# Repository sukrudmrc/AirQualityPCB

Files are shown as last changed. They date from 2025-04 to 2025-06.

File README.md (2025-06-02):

# AirQualityPCB
This PCB is designed for an air quality monitoring station, with air quality sensors and a LoRa module placed around the STM32F103.
# SYSTEM SCHEMTAIC

# 3D-PCB

# Final PCB 
pcbF

 # SENSORS

SHT31 

"The SHT31 sensor is a highly accurate and stable sensor with low power consumption."

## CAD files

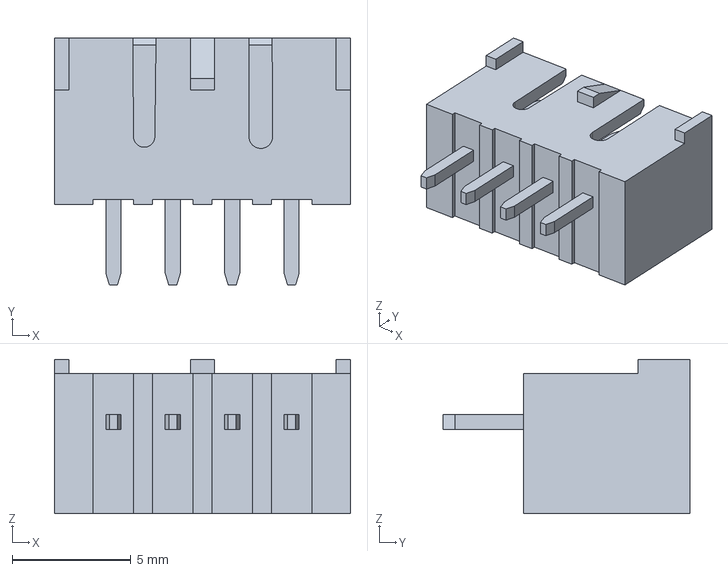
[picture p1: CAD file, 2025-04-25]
PCB_V1/my_comp/35312-0460_igs/353120460.igs
12.5 x 10.4 x 6.50 mm

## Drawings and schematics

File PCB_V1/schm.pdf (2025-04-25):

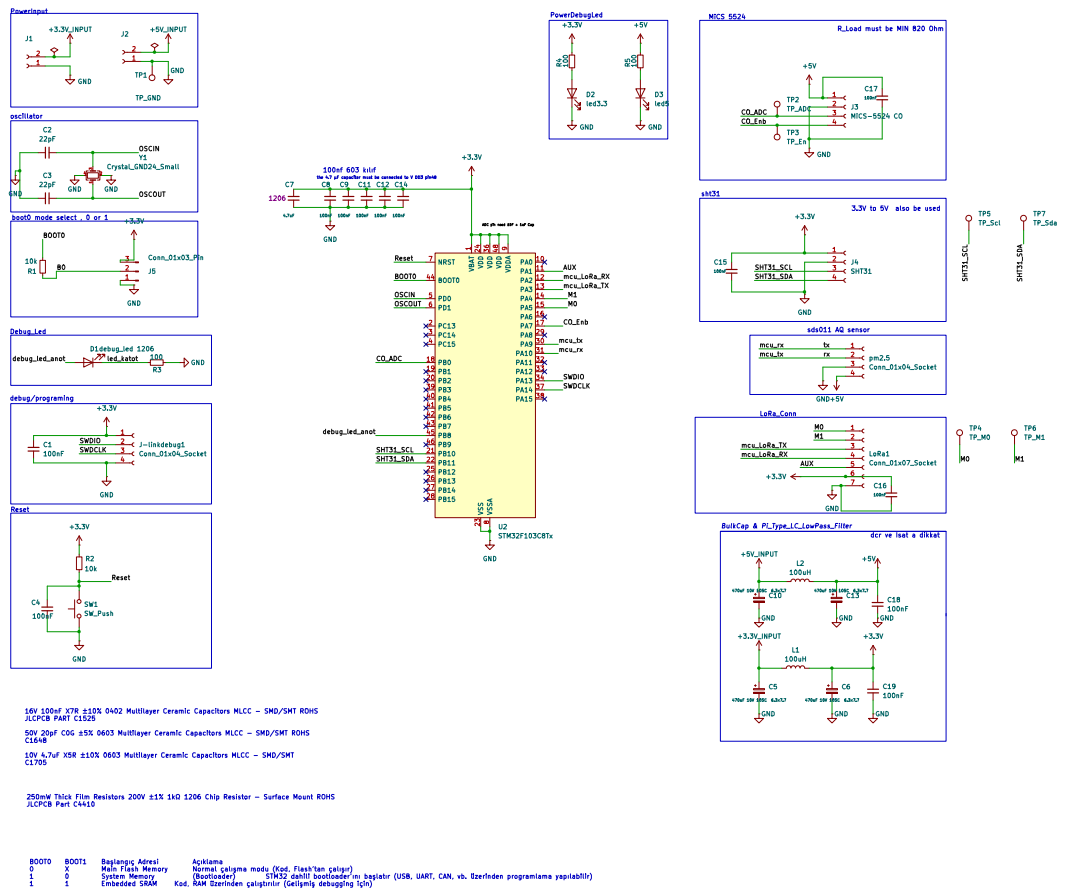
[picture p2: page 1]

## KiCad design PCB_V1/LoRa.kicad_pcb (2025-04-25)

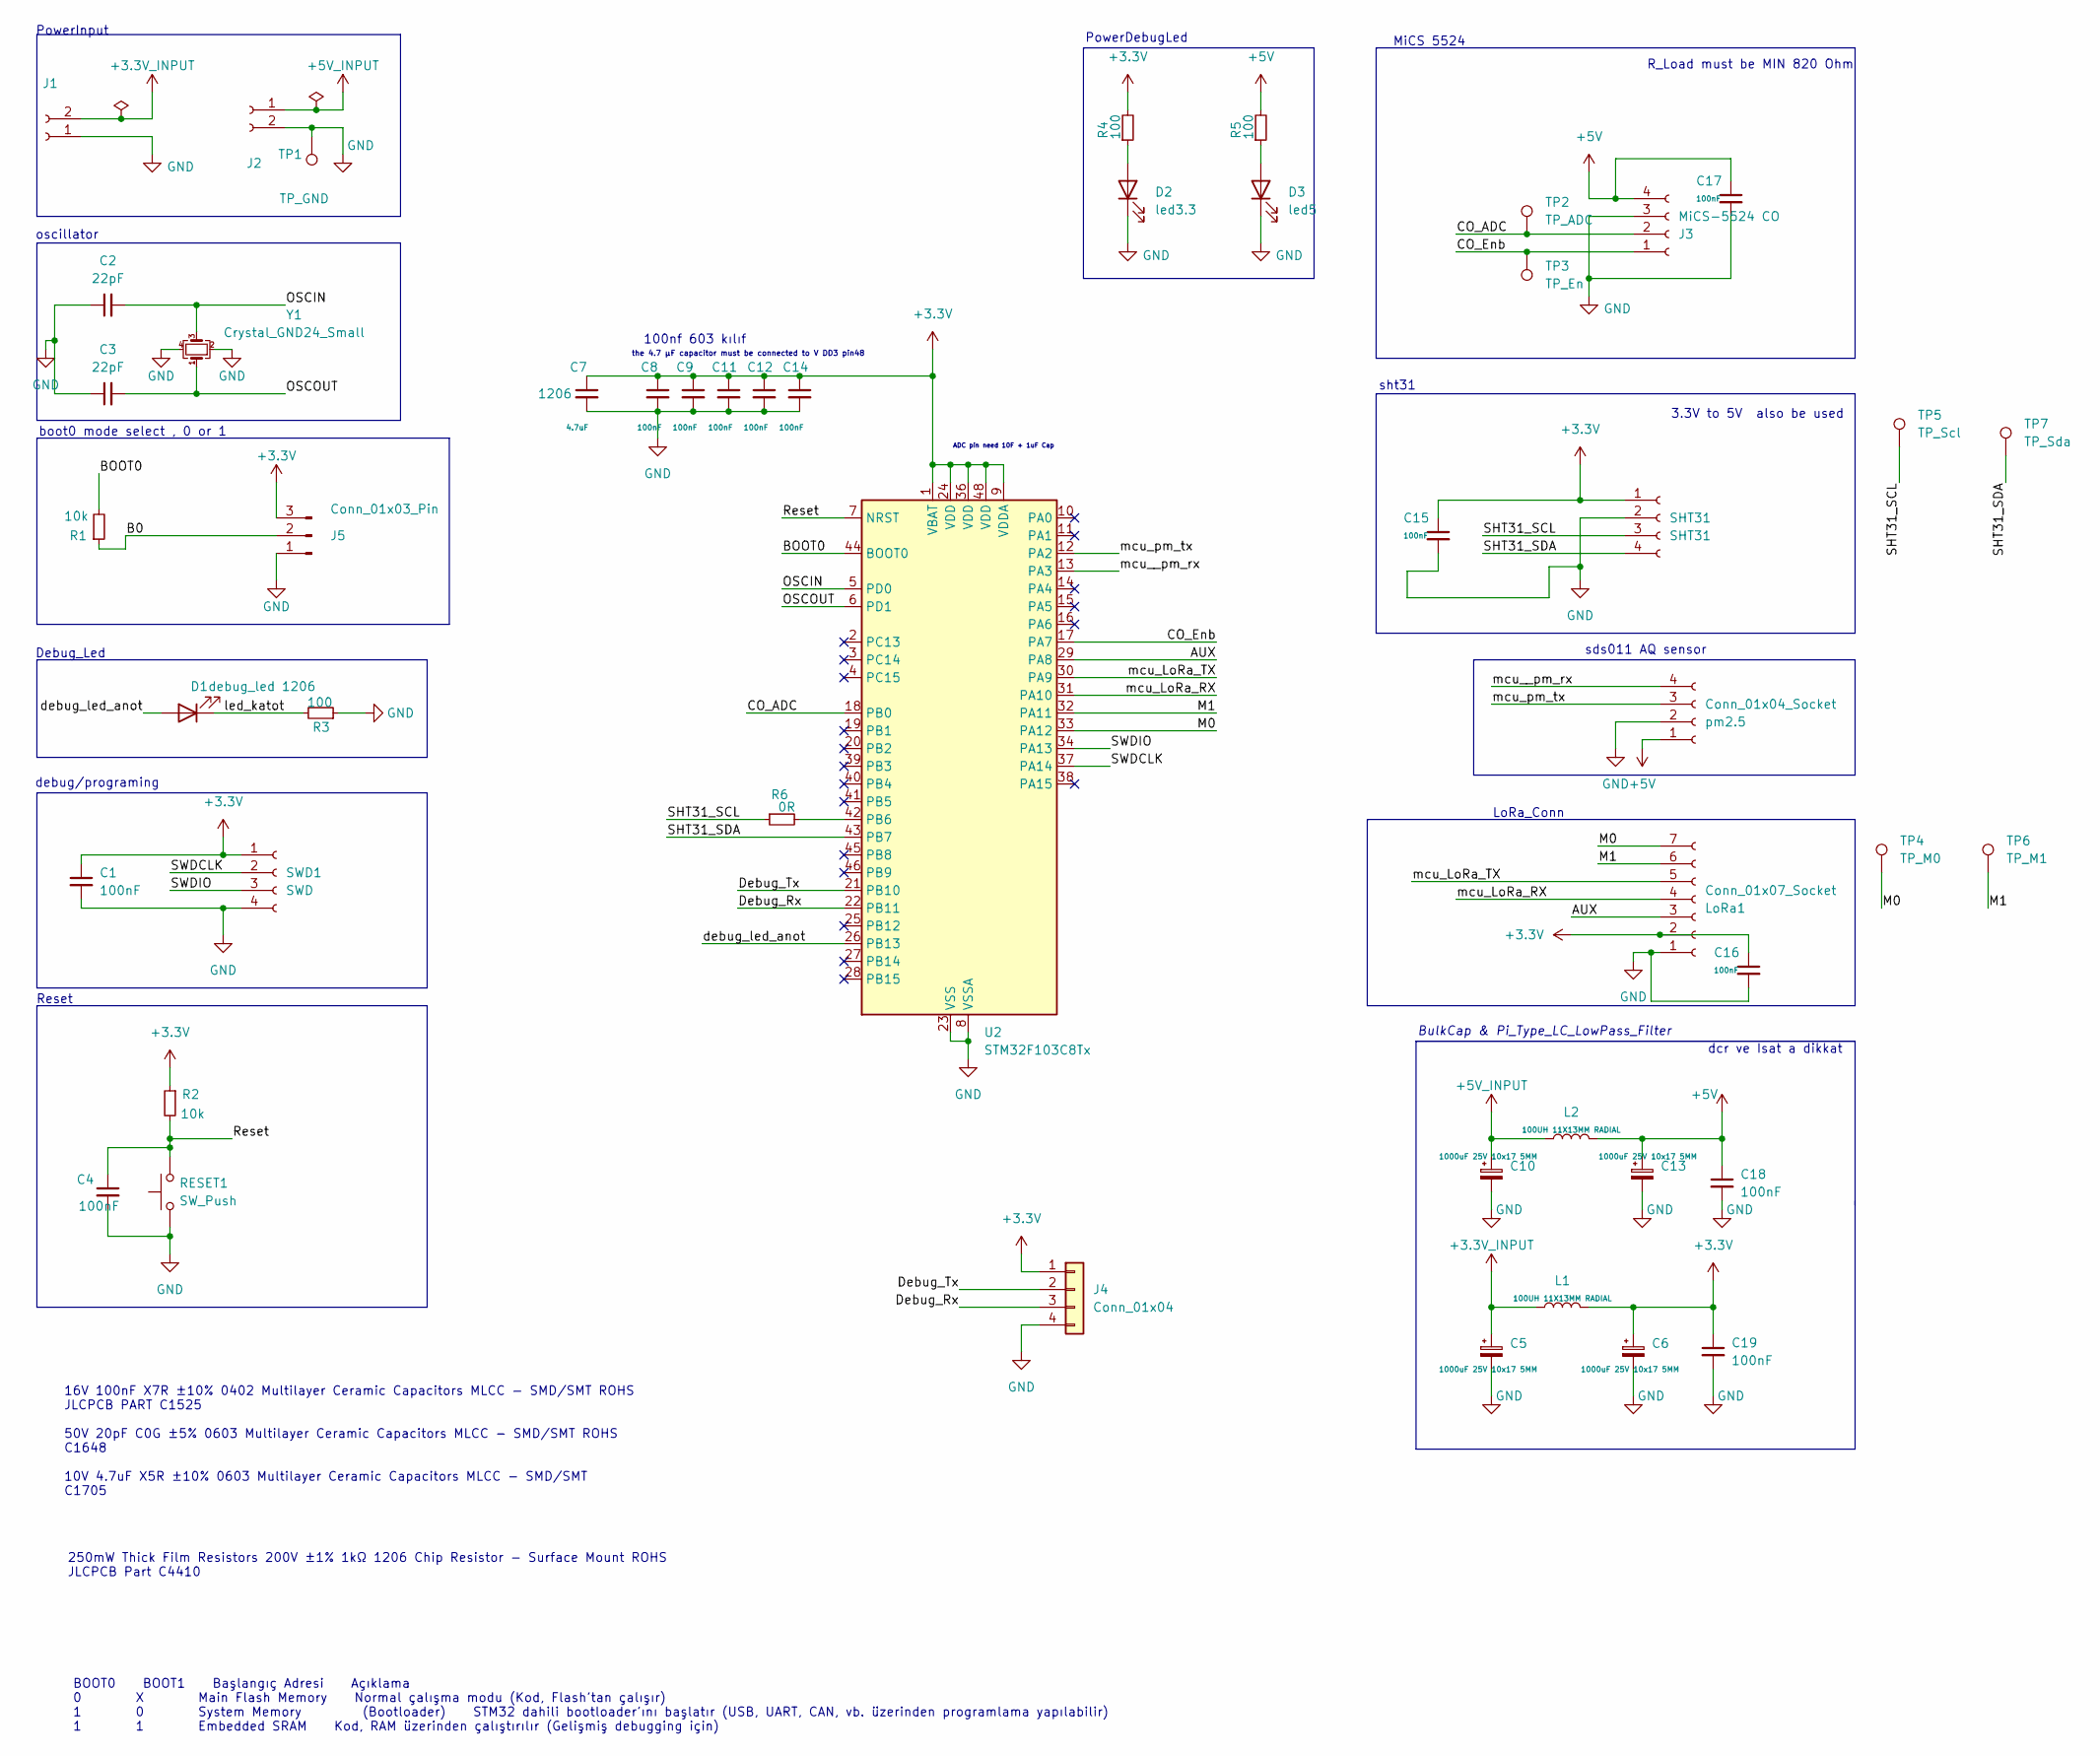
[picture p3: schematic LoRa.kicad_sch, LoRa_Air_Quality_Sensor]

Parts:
C1, C4, C8, C9, C11, C12, C14, C15, C16, C17, C18, C19: 100nF; C_0603_1608Metric_Pad1.08x0.95mm_HandSolder
C2, C3: 22pF; C_0603_1608Metric_Pad1.08x0.95mm_HandSolder
C5, C6, C10, C13: 1000uF 25V 10x17 5MM; CP_Radial_D10.0mm_P5.00mm
C7: 4.7uF; C_1206_3216Metric
D1: debug_led 1206; LED_0805_2012Metric_Pad1.15x1.40mm_HandSolder
D2: led3.3; LED_0805_2012Metric_Pad1.15x1.40mm_HandSolder
D3: led5; LED_0805_2012Metric_Pad1.15x1.40mm_HandSolder
J1: PowerInput3.3; PhoenixContact_MCV_1,5_2-G-3.5_1x02_P3.50mm_Vertical
J2: PowerInput5; PhoenixContact_MCV_1,5_2-G-3.5_1x02_P3.50mm_Vertical
J3: MiCS-5524 CO; PinSocket_1x04_P2.54mm_Vertical
J4: Conn_01x04; PinHeader_1x04_P2.54mm_Vertical
J5: Conn_01x03_Pin; SSL-12F20-G4
L1, L2: 100UH 11X13MM RADIAL; L_Radial_D10.0mm_P5.00mm_Neosid_SD12_style3
LoRa1: Conn_01x07_Socket; PinSocket_1x07_P2.54mm_Vertical
R1, R2: 10k; R_0603_1608Metric
R3: 100; R_0603_1608Metric; JLCPCB Part C4410
R4, R5: 100; R_0603_1608Metric
R6: 0R; R_0603_1608Metric
RESET1: SW_Push; DTS-3_Button
SHT31: SHT31; PinSocket_1x04_P2.54mm_Vertical
SWD1: SWD; PinHeader_1x04_P2.54mm_Vertical
TP1: TP_GND; TestPoint_Pad_2.0x2.0mm
TP2: TP_ADC; TestPoint_Pad_D1.5mm
TP3: TP_En; TestPoint_Pad_D1.5mm
TP4: TP_M0; TestPoint_Pad_D1.5mm
TP5: TP_Scl; TestPoint_Pad_D1.5mm
TP6: TP_M1; TestPoint_Pad_D1.5mm
TP7: TP_Sda; TestPoint_Pad_D1.5mm
U2: STM32F103C8Tx; LQFP-48_7x7mm_P0.5mm
Y1: Crystal_GND24_Small; Crystal_SMD_5032-4Pin_5.0x3.2mm
pm2.5: Conn_01x04_Socket; PinSocket_1x04_P2.54mm_Vertical

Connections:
+3.3V: C1.1, C6.1, C7.1, C8.1, C9.1, C11.1, C12.1, C14.1, C15.1, C16.1, C19.1, J4.1, J5.3, L1.2, LoRa1.2, R2.1, R4.2, SHT31.1, SWD1.1, U2.1 (VBAT), U2.9 (VDDA), U2.24 (VDD), U2.36 (VDD), U2.48 (VDD)
+3.3V_INPUT: C5.1, J1.2, L1.1
+5V: C13.1, C17.1, C18.1, J3.4, L2.2, R5.2, pm2.5.1
+5V_INPUT: C10.1, J2.1, L2.1
/AUX: LoRa1.3, U2.29 (PA8)
/B0: J5.2, R1.1
/BOOT0: R1.2, U2.44 (BOOT0)
/CO_ADC: J3.2, TP2.1, U2.18 (PB0)
/CO_Enb: J3.1, TP3.1, U2.17 (PA7)
/Debug_Rx: J4.3, U2.22 (PB11)
/Debug_Tx: J4.2, U2.21 (PB10)
/M0: LoRa1.7, TP4.1, U2.33 (PA12)
/M1: LoRa1.6, TP6.1, U2.32 (PA11)
/OSCIN: C2.2, U2.5 (PD0), Y1.3
/OSCOUT: C3.2, U2.6 (PD1), Y1.1
/Reset: C4.1, R2.2, RESET1.2, U2.7 (NRST)
/SHT31_SCL: R6.1, SHT31.3, TP5.1
/SHT31_SDA: SHT31.4, TP7.1, U2.43 (PB7)
/SWDCLK: SWD1.2, U2.37 (PA14)
/SWDIO: SWD1.3, U2.34 (PA13)
/debug_led_anot: D1.2 (A), U2.26 (PB13)
/led_katot: D1.1 (K), R3.2
/mcu_LoRa_RX: LoRa1.4, U2.31 (PA10)
/mcu_LoRa_TX: LoRa1.5, U2.30 (PA9)
/mcu__pm_rx: U2.13 (PA3), pm2.5.4
/mcu_pm_tx: U2.12 (PA2), pm2.5.3
GND: C1.2, C2.1, C3.1, C4.2, C5.2, C6.2, C7.2, C8.2, C9.2, C10.2, C11.2, C12.2, C13.2, C14.2, C15.2, C16.2, C17.2, C18.2, C19.2, D2.1 (K), D3.1 (K), J1.1, J2.2, J3.3, J4.4, J5.1, LoRa1.1, R3.1, RESET1.1, SHT31.2, SWD1.4, TP1.1, U2.8 (VSSA), U2.23 (VSS), U2.35 (VSS), U2.47 (VSS), Y1.2, Y1.4, pm2.5.2
unnamed: D2.2 (A), R4.1
unnamed: D3.2 (A), R5.1
unnamed: R6.2, U2.42 (PB6)

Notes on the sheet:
16V 100nF X7R ±10% 0402 Multilayer Ceramic Capacitors MLCC - SMD/SMT ROHS JLCPCB PART C1525 50V 20pF C0G ±5% 0603 Multilayer Ceramic Capacitors MLCC - SMD/SMT ROHS C1648 10V 4.7uF X5R ±10% 0603 Multilayer Ceramic Capacitors MLCC - SMD/SMT C1705
BulkCap & Pi_Type_LC_LowPass_Filter
sds011 AQ sensor
boot0 mode select , 0 or 1
3.3V to 5V also be used
BOOT0 BOOT1 Başlangıç Adresi Açıklama 0 X Main Flash Memory Normal çalışma modu (Kod, Flash'tan çalışır) 1 0 System Memory (Bootloader) STM32 dahili bootloader'ını başlatır (USB, UART, CAN, vb. üzerinden programlama yapılabilir) 1 1 Embedded SRAM Kod, RAM üzerinden çalıştırılır (Gelişmiş debugging 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
PowerDebugLed
Debug_Led
sht31
the 4.7 μF capacitor must be connected to V DD3 pin48
R_Load must be MIN 820 Ohm
ADC pin need 10F + 1uF Cap
LoRa_Conn
oscillator
dcr ve Isat a dikkat
MiCS 5524
100nf 603 kılıf
250mW Thick Film Resistors 200V ±1% 1kΩ 1206 Chip Resistor - Surface Mount ROHS JLCPCB Part C4410
debug/programing
Reset
PowerInput

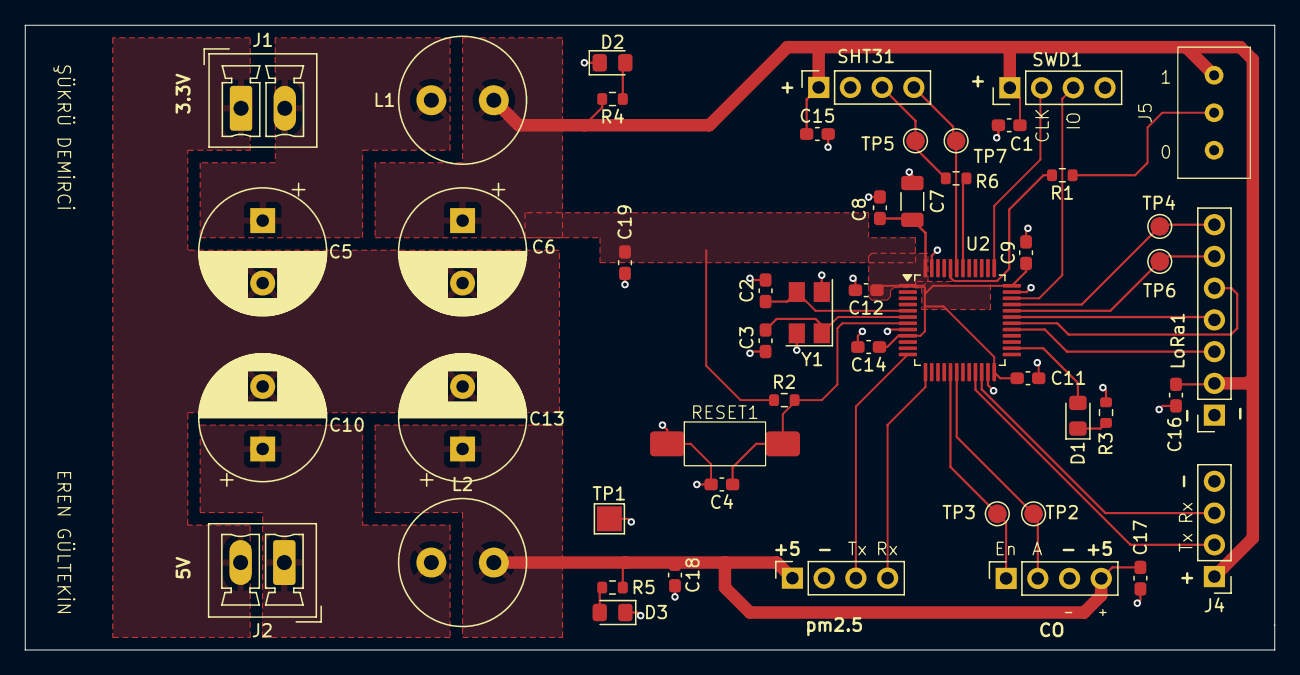
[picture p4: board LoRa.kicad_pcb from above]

Board: 2 copper layers, 100.0 x 50.0 mm, 49 parts (0 on the bottom side), 30 nets.
